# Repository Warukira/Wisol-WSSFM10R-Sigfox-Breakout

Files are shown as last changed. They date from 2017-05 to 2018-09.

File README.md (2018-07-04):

## Wisol WSSFM10R Sigfox Breakout Board

This breakout board connects your Arduino, Raspberry Pi and other devices to the Sigfox IoT network for low-power, long-range communications. The board uses the Wisol WSSFM10Rx module to connect to the Sigfox network. The interface between the device and the breakout board is based on UART Serial I/O at 9600 bps with 4 pins (3.3V, GND, TX, RX). A U.FL antenna and a Sigfox network subscription are required.

Refer to the `Hardware` folder.

- Autodesk EAGLE board and schematic for Wisol WSSFM10R2/4 Sigfox Breakout board (Sigfox Zones RCZ2 and RCZ4)

- Formatted for Seeed Fusion PCB Assembly service, so that you may submit the files from this repository and order the breakout board fully assembled with the onboard components, including the Wisol Sigfox module: <br>
  https://www.seeedstudio.com/fusion.html

- All components sourced from Seeed Open Parts Library (except for Wisol module) for quicker PCB assembly by Seeed Fusion: <br>
  https://www.seeedstudio.com/opl.html

- Original design by Sea Slug Labs: <br>
  https://github.com/SeaSlugLabs/Wisol-WSSFM10R2-Sigfox-Breakout
  
- Why I created the breakout board: <br>
  https://medium.com/@ly.lee/making-my-first-ever-pcb-with-seeed-fusion-pcb-assembly-service-9af5736016b3

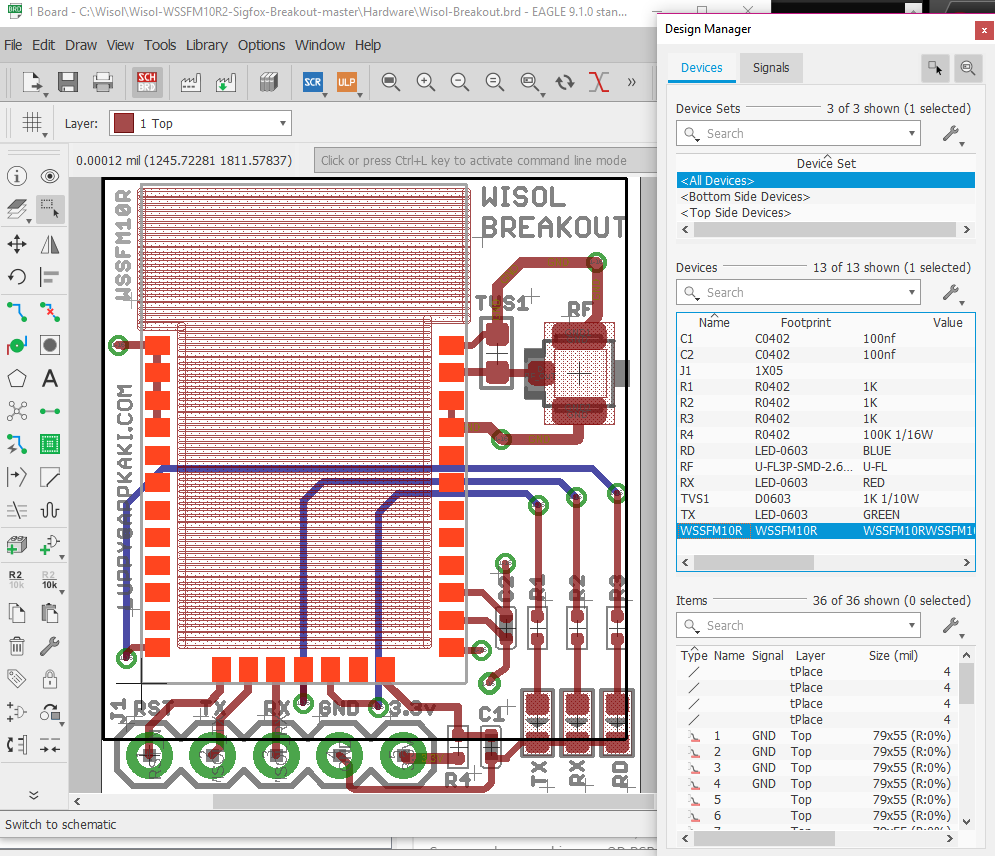
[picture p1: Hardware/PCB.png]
Wisol WSSFM10R2/4 Sigfox Breakout board


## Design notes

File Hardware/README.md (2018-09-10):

## Wisol WSSFM10R Sigfox Breakout Board

This breakout board connects your Arduino, Raspberry Pi and other devices to the Sigfox IoT network for low-power, long-range communications. The board uses the Wisol WSSFM10Rx module to connect to the Sigfox network. The interface between the device and the breakout board is based on UART Serial I/O at 9600 bps with 4 pins (3.3V, GND, TX, RX). A U.FL antenna and a Sigfox network subscription are required.

- Autodesk EAGLE board and schematic for Wisol WSSFM10R2/4 Sigfox Breakout board (Sigfox Zones RCZ2 and RCZ4) are in `Wisol-Breakout.brd` and `Wisol-Breakout.sch`

- The PCB design uses 4 layers. If you're using the Free Edition of Autodesk EAGLE, you will only see the top and bottom layers.
  Subscribe to the Standard Edition of Autodesk EAGLE to see all 4 layers.

- Formatted for Seeed Fusion PCB Assembly service, so that you may submit the files from this repository and order the breakout board fully assembled with the onboard components, including the Wisol Sigfox module: <br>
  https://www.seeedstudio.com/fusion.html

- All components sourced from Seeed Open Parts Library (except for Wisol module) for quicker PCB assembly by Seeed Fusion: <br>
  https://www.seeedstudio.com/opl.html

- PCB layout was validated in Autodesk EAGLE with the Seeed Fusion Design Rules `SeeedStudio_4layer_DRU_no_angle_20140221.dru`

- PCB design was exported from Autodesk EAGLE to Seeed Fusion in Gerber RS-274x and Excellon (drill) formats using the CAM Processor `Seeed_Gerber_Generater_4-layer_1-2-15-16.cam`

## Seeed Fusion PCB Manufacturing and Assembly

Order submitted to Seeed Fusion for PCB manufacturing and assembly at https://www.seeedstudio.com/fusion_pcb.html:

1. `Wisol-Breakout_2018-xx-xx.zip`: PCB design in Gerber RS-274x and Excellon (drill) formats

1. PCB Specifications: <br>
  PCB Dimensions - 25.4mm*21.6mm <br>
  Impedance Control - No <br>
  Surface Finish - HASL <br>
  Minimum Solder Mask Dam - 0.4mm↑ <br>
  Copper Weight - 1oz. <br>
  Plated Half-holes / Castellated Holes - No <br>
  Minimum Drill Hole Size - 0.3mm <br>
  PCB Color - Green <br>
  Base Material - FR-4 TG130 <br>
  No. of Layers - 4 layers <br>
  Blind or Buried Vias - No <br>
  PCB Thickness - 1.6 <br>
  Trace Width / Spacing - 4/4 mil <br>
  No. of Different Designs - 1 <br>

1. `Wisol-Breakout-BOM.csv`: Bill Of Materials (BOM) for Sigfox Zone RCZ4. Update the WSSFM10R Manufacturer Part Number (MPN) in the BOM if you are in other zones: <br>
  For RCZ1: WSSFM10R1AT<br>
  For RCZ2: WSSFM10R2AT<br>
  For RCZ3: WSSFM10R3AT<br>
  For RCZ4: WSSFM10R4AT<br>

1. Link provided to Seeed Fusion for sourcing WSSFM10R4AT (RCZ4): <br>																									
  https://www.avnet.com/shop/apac/products/wisol/wssfm10r4at-3074457345633583729/?aka_re=1																							

## Changes for Sigfox Zones RCZ1 and RCZ3

The design here was created for Wisol WSSFM10R2 and R4 (Sigfox Zones RCZ2 and RCZ4). For Wisol WSSFM10R1 and R3 (Sigfox Zones RCZ1 and RCZ3) the footprint is smaller and the module needs to be moved down by 5mm.  All other pins and components are unchanged.

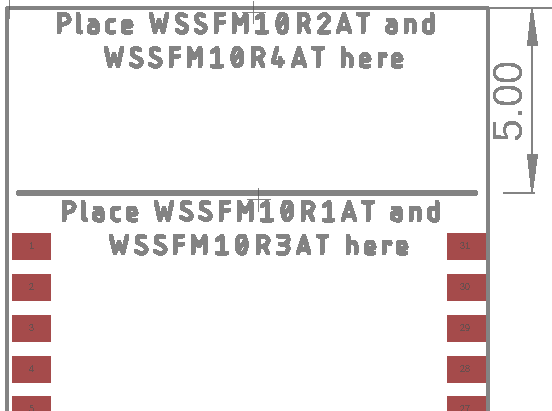
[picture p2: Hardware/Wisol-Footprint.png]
Wisol WSSFM10R Placement


## InnoComm Sigfox Breakout Board

I have created another breakout board for the InnoComm Sigfox module SN10-12:

https://github.com/lupyuen/innocomm-sigfox-breakout

## References

1. Original PCB design by Sea Slug Labs: <br>
  https://github.com/SeaSlugLabs/Wisol-WSSFM10R2-Sigfox-Breakout
  
1. Why I created the breakout board: <br>
  https://medium.com/@ly.lee/making-my-first-ever-pcb-with-seeed-fusion-pcb-assembly-service-9af5736016b3
  
1. List of all Sigfox Zones and the countries covered: <br>
  http://makers.sigfox.com/about/

1. Wisol WSSFM10R H/W Design Guide R03 170320

1. Wisol WSSFM10R4AT Datasheet REV02 170320

Wisol WSSFM10R2/4 Sigfox Breakout board

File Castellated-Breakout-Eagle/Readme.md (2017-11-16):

WSSFM10R2 Castellated Breakout Board Eagle Library

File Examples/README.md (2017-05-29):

# Arduino Examples
I use this code to test the boards. 

We use the PC serial port on the normal arduino UART pins and for the AltSoftSerial we use 9 for TX and 8 for RX

I am using the [AltSoftSerial Library](https://github.com/PaulStoffregen/AltSoftSerial), please use that one because it is already tested

The first file called Wisol_Software_Serial_Local is a simple program with the following functionality  :
- Get ID
- Get PAC
- Get Temperatue
- Send a Local frame
- Sleep
- Wake up and Loop

The next file called Wisol_Software_Serial_Local_RX is used to test the RX function. The program will just wait for incoming messages and display them on the PC Serial Port

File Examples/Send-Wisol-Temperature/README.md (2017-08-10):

## This program will send the Temperatue of the Wisol sensor over Sigfox

Some things to know:
* Always use this command AT$RC and wait for the OK before sending the Sigfox frame.
* The wisol module receives bytes formated as string AT$SF=AA 
* The Temperatues is received as Chars so we need to convert it to an Int so you can send the data in 2 bytes
* I use ATOI to make the conversion.
* To add the Integer to a string I use String(data,HEX) to put the integer into a byte string.

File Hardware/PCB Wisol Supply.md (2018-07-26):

## Shortage of Wisol Sigfox Module

Email from Seeed about shortage of Wisol Sigfox Module for RCZ4 (WSSFM10R4AT). Does anyone know how we could get 2 modules for testing the Breakout Board PCB?

-----
Created at:	Thu, Jul 26, 2018 at 3:14 PM <br>
From:	_(removed)_@seeed.cc <br>
To:	luppy@appkaki.com <br>
Subject:	Seeed order 180703171002-A859414 <br>

Dear Luppy,

Your order 180703171002-A859414 has been finished except the part(WSSFM10R4AT) unsoldering. 
The part is short in supply, and we are incapable to get it.

Is there any subsidiary for it?

Or could you buy and ship it to us? Seeed will pay for you.

Or could we leave the location out?

So sorry for the inconvenience!

Thank you!

Best regards!

_(removed)_ <br>
Project Manager <br>
Seeed Fusion Team <br>
Seeed Technology Co., Ltd <br>
深圳矽递科技有限公司 <br>

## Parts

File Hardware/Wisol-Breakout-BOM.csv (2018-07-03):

Designator | Manufacturer Part Number | Quantity
C1,C2 | CC0402KRX7R8BB104 | 2
C3 | CC0402JRNPO9BN101 | 1
L1 | LQW15AN47NJ00D | 1
R1,R2,R3 | RC0402FR-071KL | 3
R4 | RC0402JR-07100KL | 1
R5 | RC0402JR-070RL | 1
RD | 19-217-BHC-ZL1M2RY-3T | 1
RF | 320110048 | 1
RX | 19-217-R6C-AL1M2VY-3T | 1
TX | 19-217-G7C-AN1P2-3T | 1
WSSFM10R | WSSFM10R4AT | 1

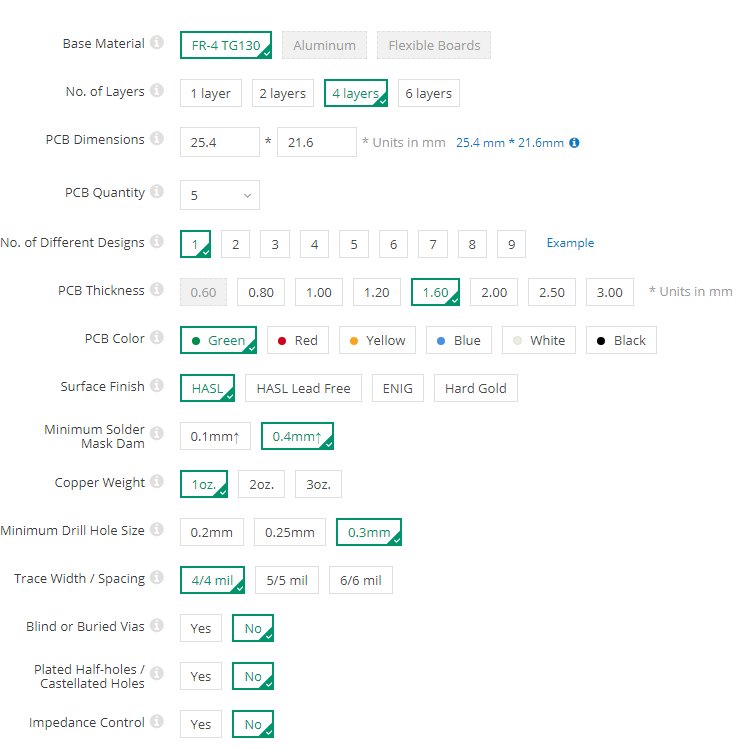
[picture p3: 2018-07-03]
Hardware/PCB Order.png

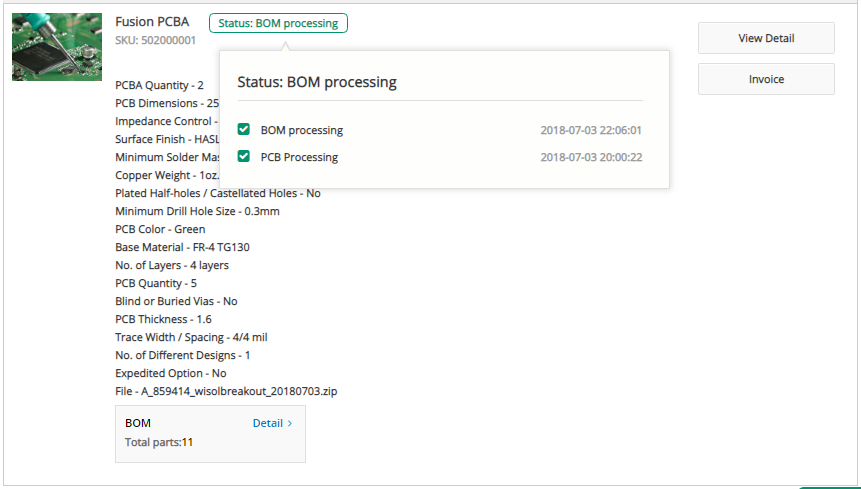
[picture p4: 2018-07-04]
Hardware/PCB Order Confirmation.png

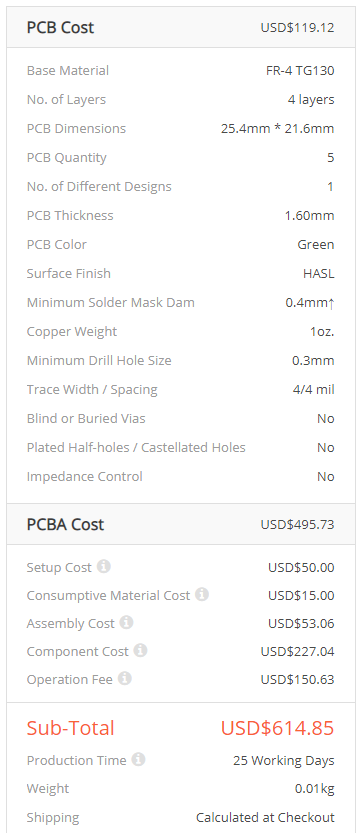
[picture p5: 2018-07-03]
Hardware/PCB Cost.png

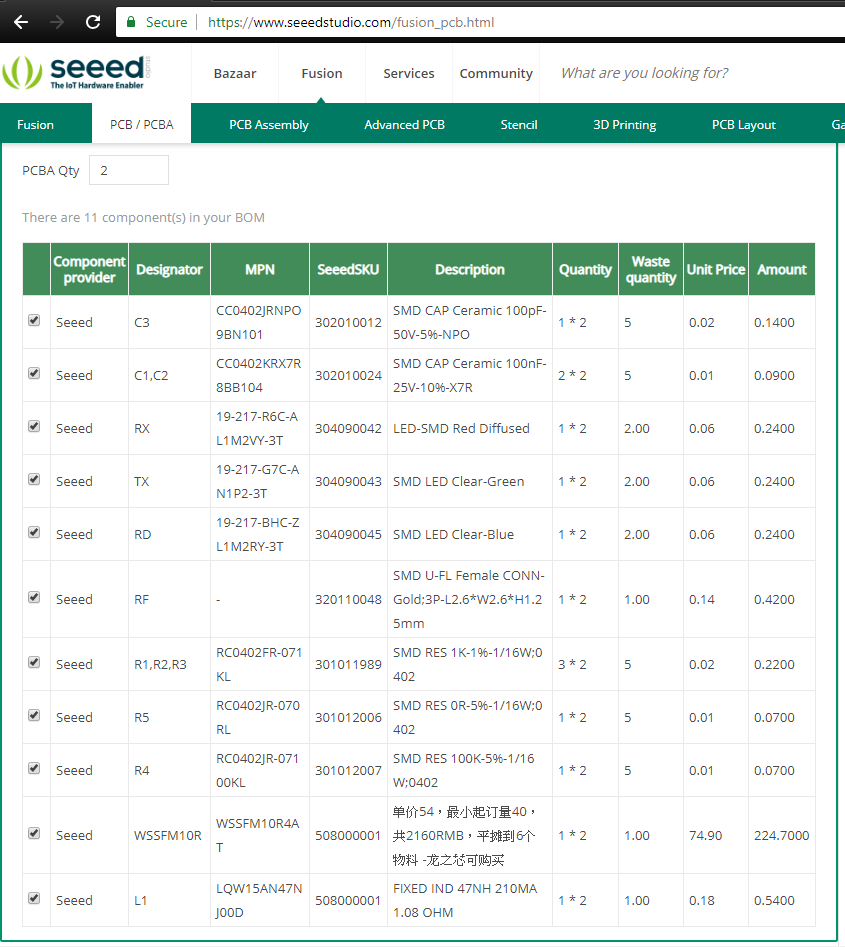
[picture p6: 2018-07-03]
Hardware/PCB BOM Cost.png

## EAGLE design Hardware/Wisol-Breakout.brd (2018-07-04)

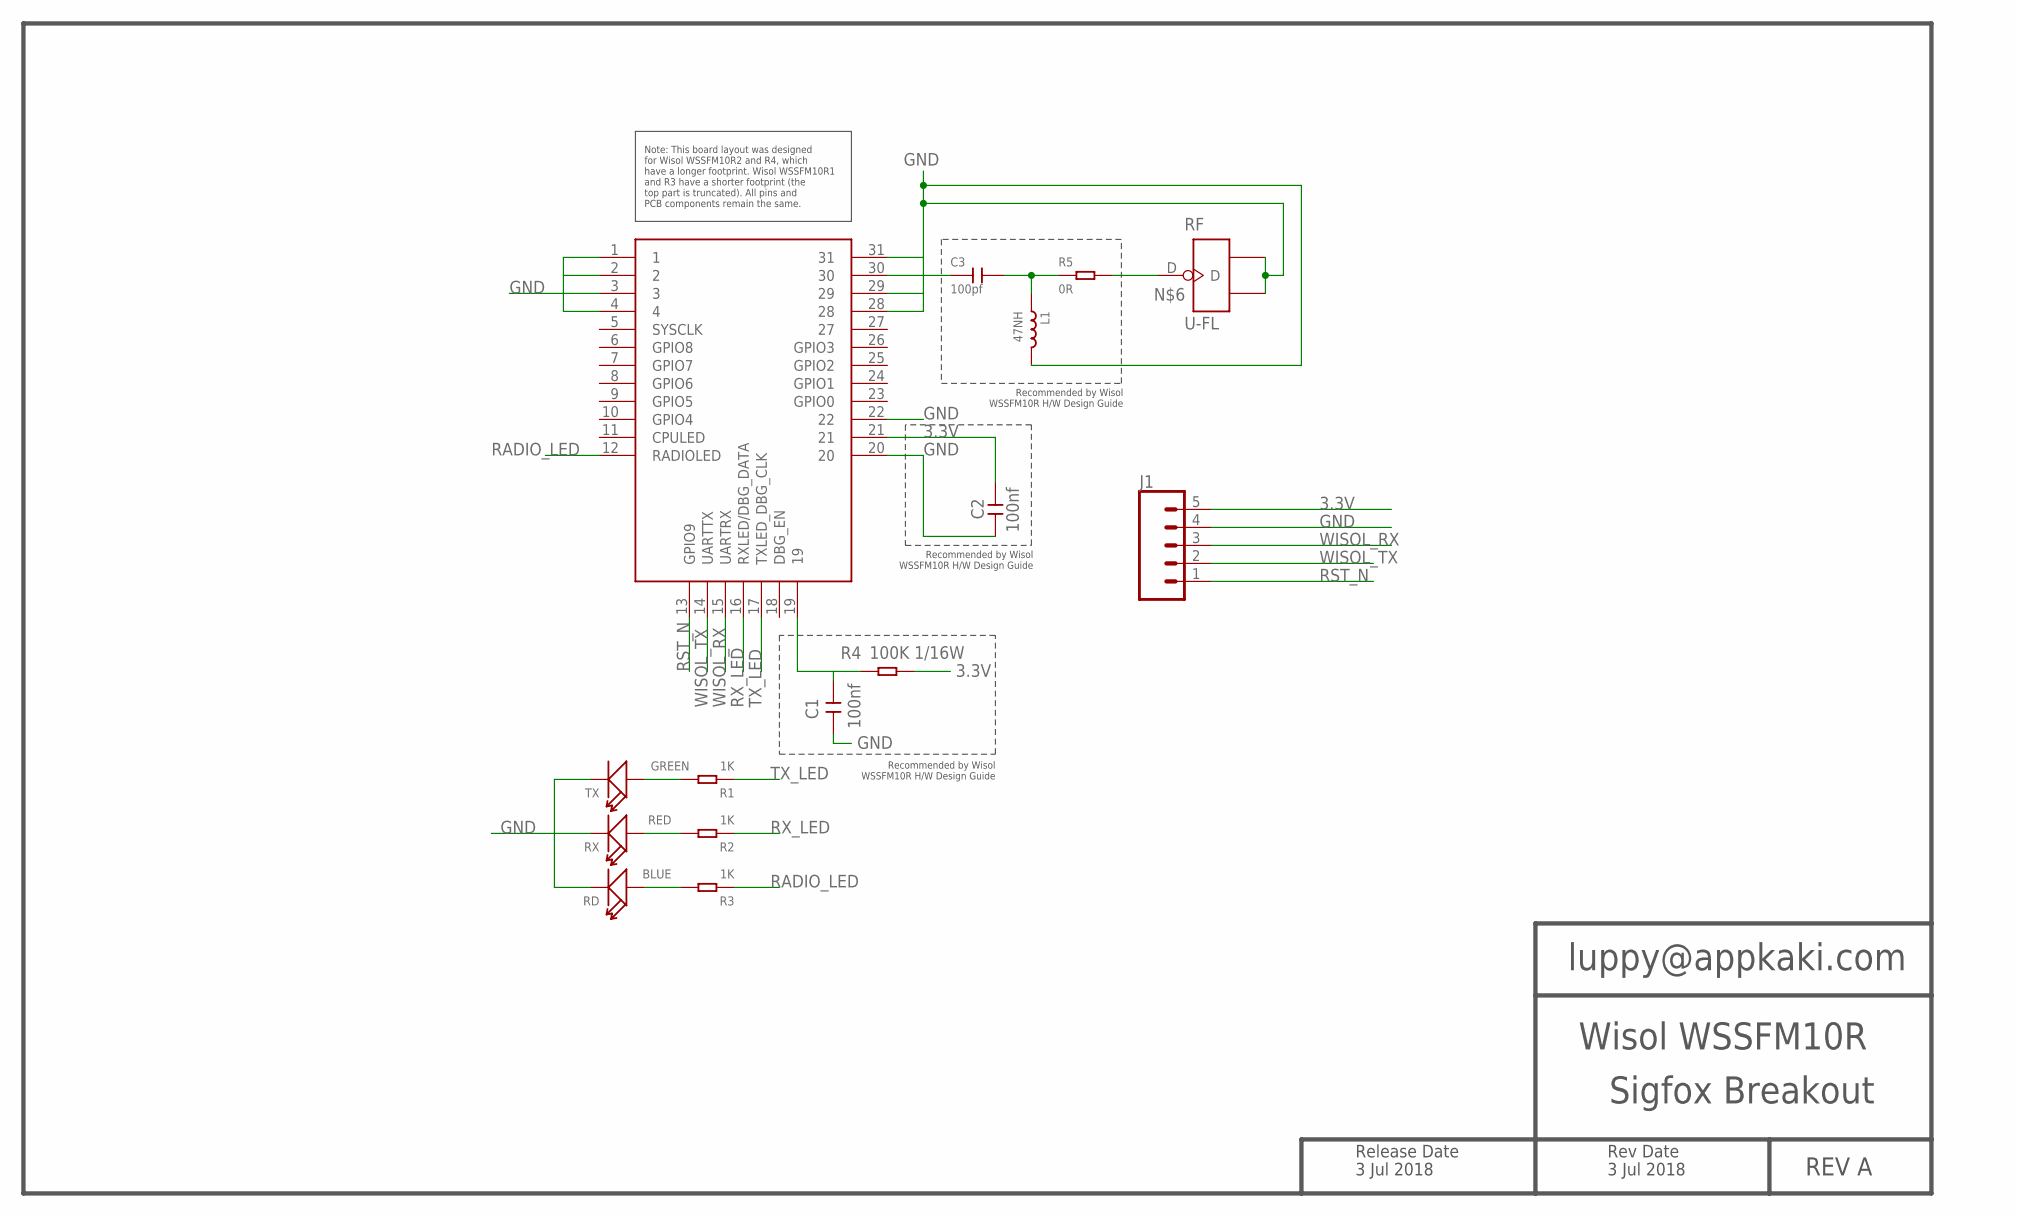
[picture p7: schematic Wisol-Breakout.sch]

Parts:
C1, C2: 100nf; C0402
C3: 100pf; C0402
J1: CONN_05; 1X05
L1: 47NH; L0402; MPN LQW15AN47NJ00D
R1, R2, R3: 1K; R0402; MPN RC0402FR-071KL
R4: 100K 1/16W; R0402
R5: 0R; R0402
RD: BLUE; LED-0603
RF: U-FL; U-FL3P-SMD-2.6X2.6X1.0MM
RX: RED; LED-0603
TX: GREEN; LED-0603
WSSFM10R: WSSFM10RWSSFM10R2R4; WSSFM10R

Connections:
3.3V: C2.2, J1.5, R4.2, WSSFM10R.21
GND: C1.1, C2.1, J1.4, L1.2, RD.-, RF.GND1, RF.GND2, RX.-, TX.-, WSSFM10R.1, WSSFM10R.2, WSSFM10R.3, WSSFM10R.4, WSSFM10R.20, WSSFM10R.22, WSSFM10R.28, WSSFM10R.29, WSSFM10R.31
unnamed: C1.2, R4.1, WSSFM10R.19
unnamed: R1.2, TX.+
unnamed: R2.2, RX.+
unnamed: R3.2, RD.+
unnamed: C3.2, L1.1, R5.1
unnamed: R5.2, RF.D
RADIO_LED: R3.1, WSSFM10R.12 (RADIOLED)
RF_OUT: C3.1, WSSFM10R.30
RST_N: J1.1, WSSFM10R.13 (GPIO9)
RX_LED: R2.1, WSSFM10R.16 (RXLED/DBG_DATA)
TX_LED: R1.1, WSSFM10R.17 (TXLED_DBG_CLK)
WISOL_RX: J1.3, WSSFM10R.15 (UARTRX)
WISOL_TX: J1.2, WSSFM10R.14 (UARTTX)

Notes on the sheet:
luppy@appkaki.com
Wisol WSSFM10R
REV A
Sigfox Breakout
Release Date
3 Jul 2018
Rev Date
Note: This board layout was designed for Wisol WSSFM10R2 and R4, which have a longer footprint. Wisol WSSFM10R1 and R3 have a shorter footprint (the top part is truncated). All pins and PCB components remain the same.
Recommended by Wisol WSSFM10R H/W Design Guide

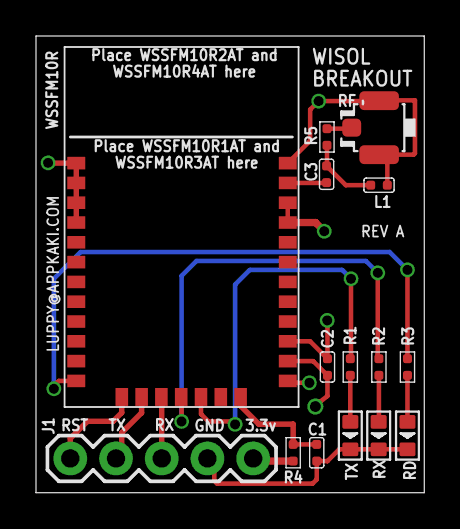
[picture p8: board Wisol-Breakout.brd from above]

Board: 4 copper layers, 21.6 x 25.4 mm, 15 parts (0 on the bottom side), 15 nets.

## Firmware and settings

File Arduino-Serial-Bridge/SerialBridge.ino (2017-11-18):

#include <AltSoftSerial.h>
// AltSoftSerial always uses these pins:
//
// Board          Transmit  Receive   PWM Unusable
// -----          --------  -------   ------------
// Teensy 3.0 & 3.1  21        20         22
// Teensy 2.0         9        10       (none)
// Teensy++ 2.0      25         4       26, 27
// Arduino Uno        9         8         10
// Arduino Leonardo   5        13       (none)
// Arduino Mega      46        48       44, 45
// Wiring-S           5         6          4
// Sanguino          13        14         12

// I am using Arduino Pro Mini which will be Arduino Uno Equivalent
AltSoftSerial mySerial;

#define Wreset 4

void setup() {

  pinMode(Wreset,OUTPUT);//I am using pin 4 to do the Sleep
  Serial.begin(9600);// Configuring the PC serial port

  mySerial.begin(9600);//Configuring the Sigfox Module software serial port

  while (!Serial) {
    
  }

  Serial.println("INITIALIZING PROGRAM");  
 
  }

void loop() {
  
 if (mySerial.available()) {
    Serial.write(mySerial.read());
  }
  if (Serial.available()) {
    mySerial.write(Serial.read());
  }
  
}

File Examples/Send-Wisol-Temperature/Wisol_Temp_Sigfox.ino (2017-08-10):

#include <AltSoftSerial.h>
#include <stdio.h>
// AltSoftSerial always uses these pins:
//
// Board          Transmit  Receive   PWM Unusable
// -----          --------  -------   ------------
// Teensy 3.0 & 3.1  21        20         22
// Teensy 2.0         9        10       (none)
// Teensy++ 2.0      25         4       26, 27
// Arduino Uno        9         8         10
// Arduino Leonardo   5        13       (none)
// Arduino Mega      46        48       44, 45
// Wiring-S           5         6          4
// Sanguino          13        14         12

// I am using Arduino Pro Mini which will be Arduino Uno Equivalent
// 


AltSoftSerial mySerial;

#define Wreset 4
String rx_wisol;


int temperaturewisol;
char wtemp[]="11111";


void setup() {

  pinMode(Wreset,OUTPUT);              //I am using pin 12 to do the Sleep
  digitalWrite(Wreset,HIGH);           //We pull it back to high


  Serial.begin(57600);                // Configuring the PC serial port
  mySerial.begin(9600);               //Configuring the Sigfox Module software serial port

  

  Serial.println("INITIALIZING PROGRAM");

  
}




void loop()
{
    //---Send AT Command
    Serial.println("Send AT Command ");
    ATcmd();                               //call AT function
    
    ReadWisol(rx_wisol);                   //Read Wisol Serial Port
    Serial.println("Wisol Response");
    Serial.print(rx_wisol);               //Print sigfox data on PC Serial port

    Serial.println("Send ID Command ");
    ATgetid();                            //call ID function
    
    ReadWisol(rx_wisol);
    Serial.println("Wisol Response");
    Serial.print(rx_wisol);

    Serial.println("Send PAC Command ");
    ATgetpac();                           //call PAC function

    ReadWisol(rx_wisol);
    Serial.println("Wisol Response");
    Serial.print(rx_wisol);


    Serial.println("******Wisol temp******");
    ATtemp();                            //call ATtemp
    ReadWisolTemp();                     //i use a different function to read the temperature                                   
    Serial.println("Wisol Response");
    Serial.println(wtemp);               //Temperature as Char array

    temperaturewisol=atoi(wtemp);        //Char to Int Conversion
//----Send Sigfox data
    Serial.println("Send Sigfox");    

    ATRC();                              // We do the AT$RC command first
    ReadWisolTx(rx_wisol);
    Serial.println("Wisol Response");
    Serial.print(rx_wisol);
    
    ATsendsigfoxint(temperaturewisol);  // Function to send a Sigfox Integer     

    delay(10);
    ReadWisolTx(rx_wisol);              // call different function to read wisol serial after sigfox transmision
                                        // we will wait for the transmission to complete
    delay(50);
    Serial.print(rx_wisol);
    Serial.println("");
    Serial.println("");
    delay(100);

    Serial.println("Send AT Command ");
    ATcmd();
    delay(100);
    ReadWisol(rx_wisol);
    Serial.println("Wisol Response");
    Serial.print(rx_wisol);


  // Apply the desired delay after sending
  // this is a 11 minute dirty delay for my testing purposes
   for (int i=0; i <= 11; i++){
     
   
    delay(10000);
    delay(10000);
    delay(10000);
    delay(10000);
    delay(10000);
    delay(10000);
    delay(10000);
   }

}

//+++++++++FUNCTIONS++++++++++++++++++++++++++++++
void ATtemp()
{

  delay(5);
  mySerial.println("AT$T?");// Command to get Temperature
  delay(100);



}



void ATgetid()
{

  delay(5);
  mySerial.println("AT$I=10");// Command to get ID
  delay(100);

}


void ATgetpac()
{

  delay(5);
  mySerial.println("AT$I=11");// Command to get PAC
  delay(100);


}

void ATcmd()
{

  mySerial.println("AT");// writing AT command
  delay(100);

}

void ATGI()
{

  mySerial.println("AT$GI?");// writing AT command
  delay(100);

}

void ATRC()
{

  mySerial.println("AT$RC");// writing AT command
  delay(100);

}

void ATsendlocal()
{
mySerial.println("AT$SL=AABBCCDDFF11228899");
}



void ATsendsigfoxint(int data)
{
  //To transmit the wisol modules need to have the byte complete
  // on the int to string conversion if number is 3 digit the function will not
  //add the 0 on the left for example 258 decimal is 102 on HEX, but the module with  give you 
  // a parse error if you try to send AT$SF=102.. the correct way is AT$SF=0102
  // on the switch function  we detect the lenght of the conversion and add the zeroes to the left.
  
  String Sigfox="AT$SF="; 
  String tempdata=String(data,HEX);

  switch(tempdata.length())
  {
    case 1:
            Sigfox+="000"+String(data,HEX);
            break;
    case 2:
            Sigfox+="00"+String(data,HEX);
            break;
    case 3:
            Sigfox+="0"+String(data,HEX);
            break;
    case 4:
            Sigfox+=String(data,HEX);
            break;
    default:
            // no match
            break;
      
  }
  
  Serial.println("Data to send to sigfox "+Sigfox);
  
  mySerial.println(Sigfox);
  delay(100);

}
void ATsendsigfox()
{
mySerial.println("AT$SF=AABBCCDDEEFFAABBCCDDEEFF");
}


void ReadWisol(String &dest)
{
   char inData[20]; // Allocate some space for the string
   char inChar; // Where to store the character read
   byte index = 0; // Index into array; where to store the character


      delay(200);
     if (mySerial.available()>0)
      {
              while(mySerial.available()>0)
                  {

                      inChar = mySerial.read(); // Read a character
                      inData[index] = inChar; // Store it
                      index++; // Increment where to write next
                     // inData[index] = '\0'; // Null terminate the string

                    //We read from the sigfox module and put what it was read on the pc serial port
                    //Serial.write(mySerial.read());// we should get an OK,
                  }


     }
     dest=inData;




}

void ReadWisolTx(String &dest)
{
   char inData[20]; // Allocate some space for the string
   char inChar; // Where to store the character read
   byte index = 0; // Index into array; where to store the character

   while(mySerial.available()==0)
                  {
                     // we loop in here until the sigfox transmission ends.
                  }


      delay(200);
     if (mySerial.available()>0)
      {
              while(mySerial.available()>0)
                  {

                      inChar = mySerial.read(); // Read a character
                      inData[index] = inChar; // Store it
                      index++; // Increment where to write next
                     // inData[index] = '\0'; // Null terminate the string

                    //We read from the sigfox module and put what it was read on the pc serial port
                    //Serial.write(mySerial.read());// we should get an OK,
                  }


     }
     dest=inData;




}
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

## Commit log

2017-05-05 Add Hardware Files
    [WisolWSSFM10R2-Breakout.brd, WisolWSSFM10R2-Breakout.sch]
2017-05-29 Arduino Local Test
2017-05-29 Arduino Local Receive Test
2017-07-23 Program to send temperature of the wisol
    Program to send the temperature over the sigfox network.
2018-07-02 Updated for Seeed PCB Assembly
    [Wisol-Breakout-BOM.csv, Wisol-Breakout.brd, Wisol-Breakout.sch]
2018-07-02 Added Seeed DRU and Gerber Generator
2018-07-03 Added RF inductor as recommended by Wisol H/W Design Guide
    [Wisol-Breakout-BOM.csv, Wisol-Breakout.brd, Wisol-Breakout.sch]
2018-07-03 Added revision
    [Wisol-Breakout.brd, Wisol-Breakout.sch]
2018-07-04 Updated footprint for Wisol WSSFM10R1, R3
    [Wisol-Breakout.brd, Wisol-Breakout.sch]
2018-07-04 Updated Wisol footprint
2018-07-04 Added annotations for Wisol WSSFM10R H/W Design Guide
    [Wisol-Breakout.brd, Wisol-Breakout.sch]

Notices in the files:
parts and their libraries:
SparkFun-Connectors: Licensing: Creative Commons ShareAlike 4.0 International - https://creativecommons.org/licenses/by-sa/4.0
